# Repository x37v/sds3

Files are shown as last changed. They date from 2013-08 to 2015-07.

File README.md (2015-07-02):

sds3
====

SDS3 clone project - these files have not been succesfully built yet

Long thread on electro-music.com that led to fixes in the original schematic from boardmember Theff, and a working SMT run from xpmtl
http://electro-music.com/forum/topic-16985.html&postorder=asc

some troubleshooting info here: http://electro-music.com/forum/topic-16985-300.html

xpmtl's SMT design is here:
http://xpmtl.net/sdiy/projects/simmons-sds-3-voice/

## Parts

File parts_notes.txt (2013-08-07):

a 2 of 1uF: 	C10, C11
2 of 10u: 	C100, C101
a 1 of 220P: 	C14
a 5 of 100n: 	C2, C13, C15, C102, C103
1 of 470n: 	C3
a 1 of 2N2: 	C4
a 1 of 10uF: 	C5
a 4 of 10n: 	C6, C7, C8, C9
4 of 1N4148_-3: 	D1, D2, D3, D4

3 of 100K: 	[TRIM] GAIN, NULL, OFFSET, 
1 of 47ka: 	DECAY
5 of 100K BEND, DEPTH, IMPACT, PITCH, RATE
1 of 22k: 	TONE

a 4 of LM1458N: 	IC1, IC2, IC3, IC7
a 1 of LM301H: 	IC11
3 of CA3046: 	IC4, IC5, IC6
1 of CA3080LMN: 	IC8

*2 of FB_110: 	L1, L2

ORIGINALLY
	R64: 5.6K
	R65: 3.3K

7 of 100K: R16, R30, R33, R74, R75, R100*, R102
1 of 68R: 	R*
*4 of 390K: 	R11, R14, R55, R69
*3 of 270K: 	R12, R13, R22
*3 of 3K3: 	R18, R41, R104
*5 of 56K: 	R21, R32, R38, R48, R49
4 of 68K: 	R24, R28, R106, R107
7 of 470R: 	R25, R44, R45, R46, R67, R71, R73
*2 of 820R: 	R34, R39
*2 of 22K: 	R35, R56
*7 of 1K: 	R36, R37, R40, R42, R57, R64, R65
*1 of 1K8: 	R43
1 of 3K9: 	R47 [jesse stuffed]
*6 of 150K: 	R5, R6, R8, R23, R27, R29
*6 of 10K: 	R50, R51, R60, R61, R68, R100
*1 of 2M7: 	R52
*1 of 820K: 	R53
*2 of 33K: 	R70, R105
*1 of 10M: 	R76
*3 of 1M: 	R9, R10, R62

1 of shape: 	S1
1 of speed: 	S2
1 of on/off: 	S3
a 2 of BC557B: 	T2, T7
a 3 of 2N5172: 	T3, T6, T8
a 2 of 2N5459: 	T4, T5  [pull off old board]
1 of 057-010-1: 	X1

trimmer holes are too small and only support pins on a line
pads on some of the 8 pin ics are small
r32, r27 labels ambigious
r43 label illegible

need:
68R
68k
470R
3.9K
8 pin sockets
better trimmers: 72-T93YA-100K 
470nF cap [0.47u]

c2, t2 label could be better
c100 and c101 have weird package on board [and should be labeled uF]
Original values for R64 and 65 [add stars?]
R100* is starred because it is fixed at 100K but was part of the run generator before
Actually, there is an R100 and R100*
D7 via is SO close!
S3 and S2 should only have 2 pads
trimmers should be 1 turn..

Alex stuffed 47KA pot with 50K linear

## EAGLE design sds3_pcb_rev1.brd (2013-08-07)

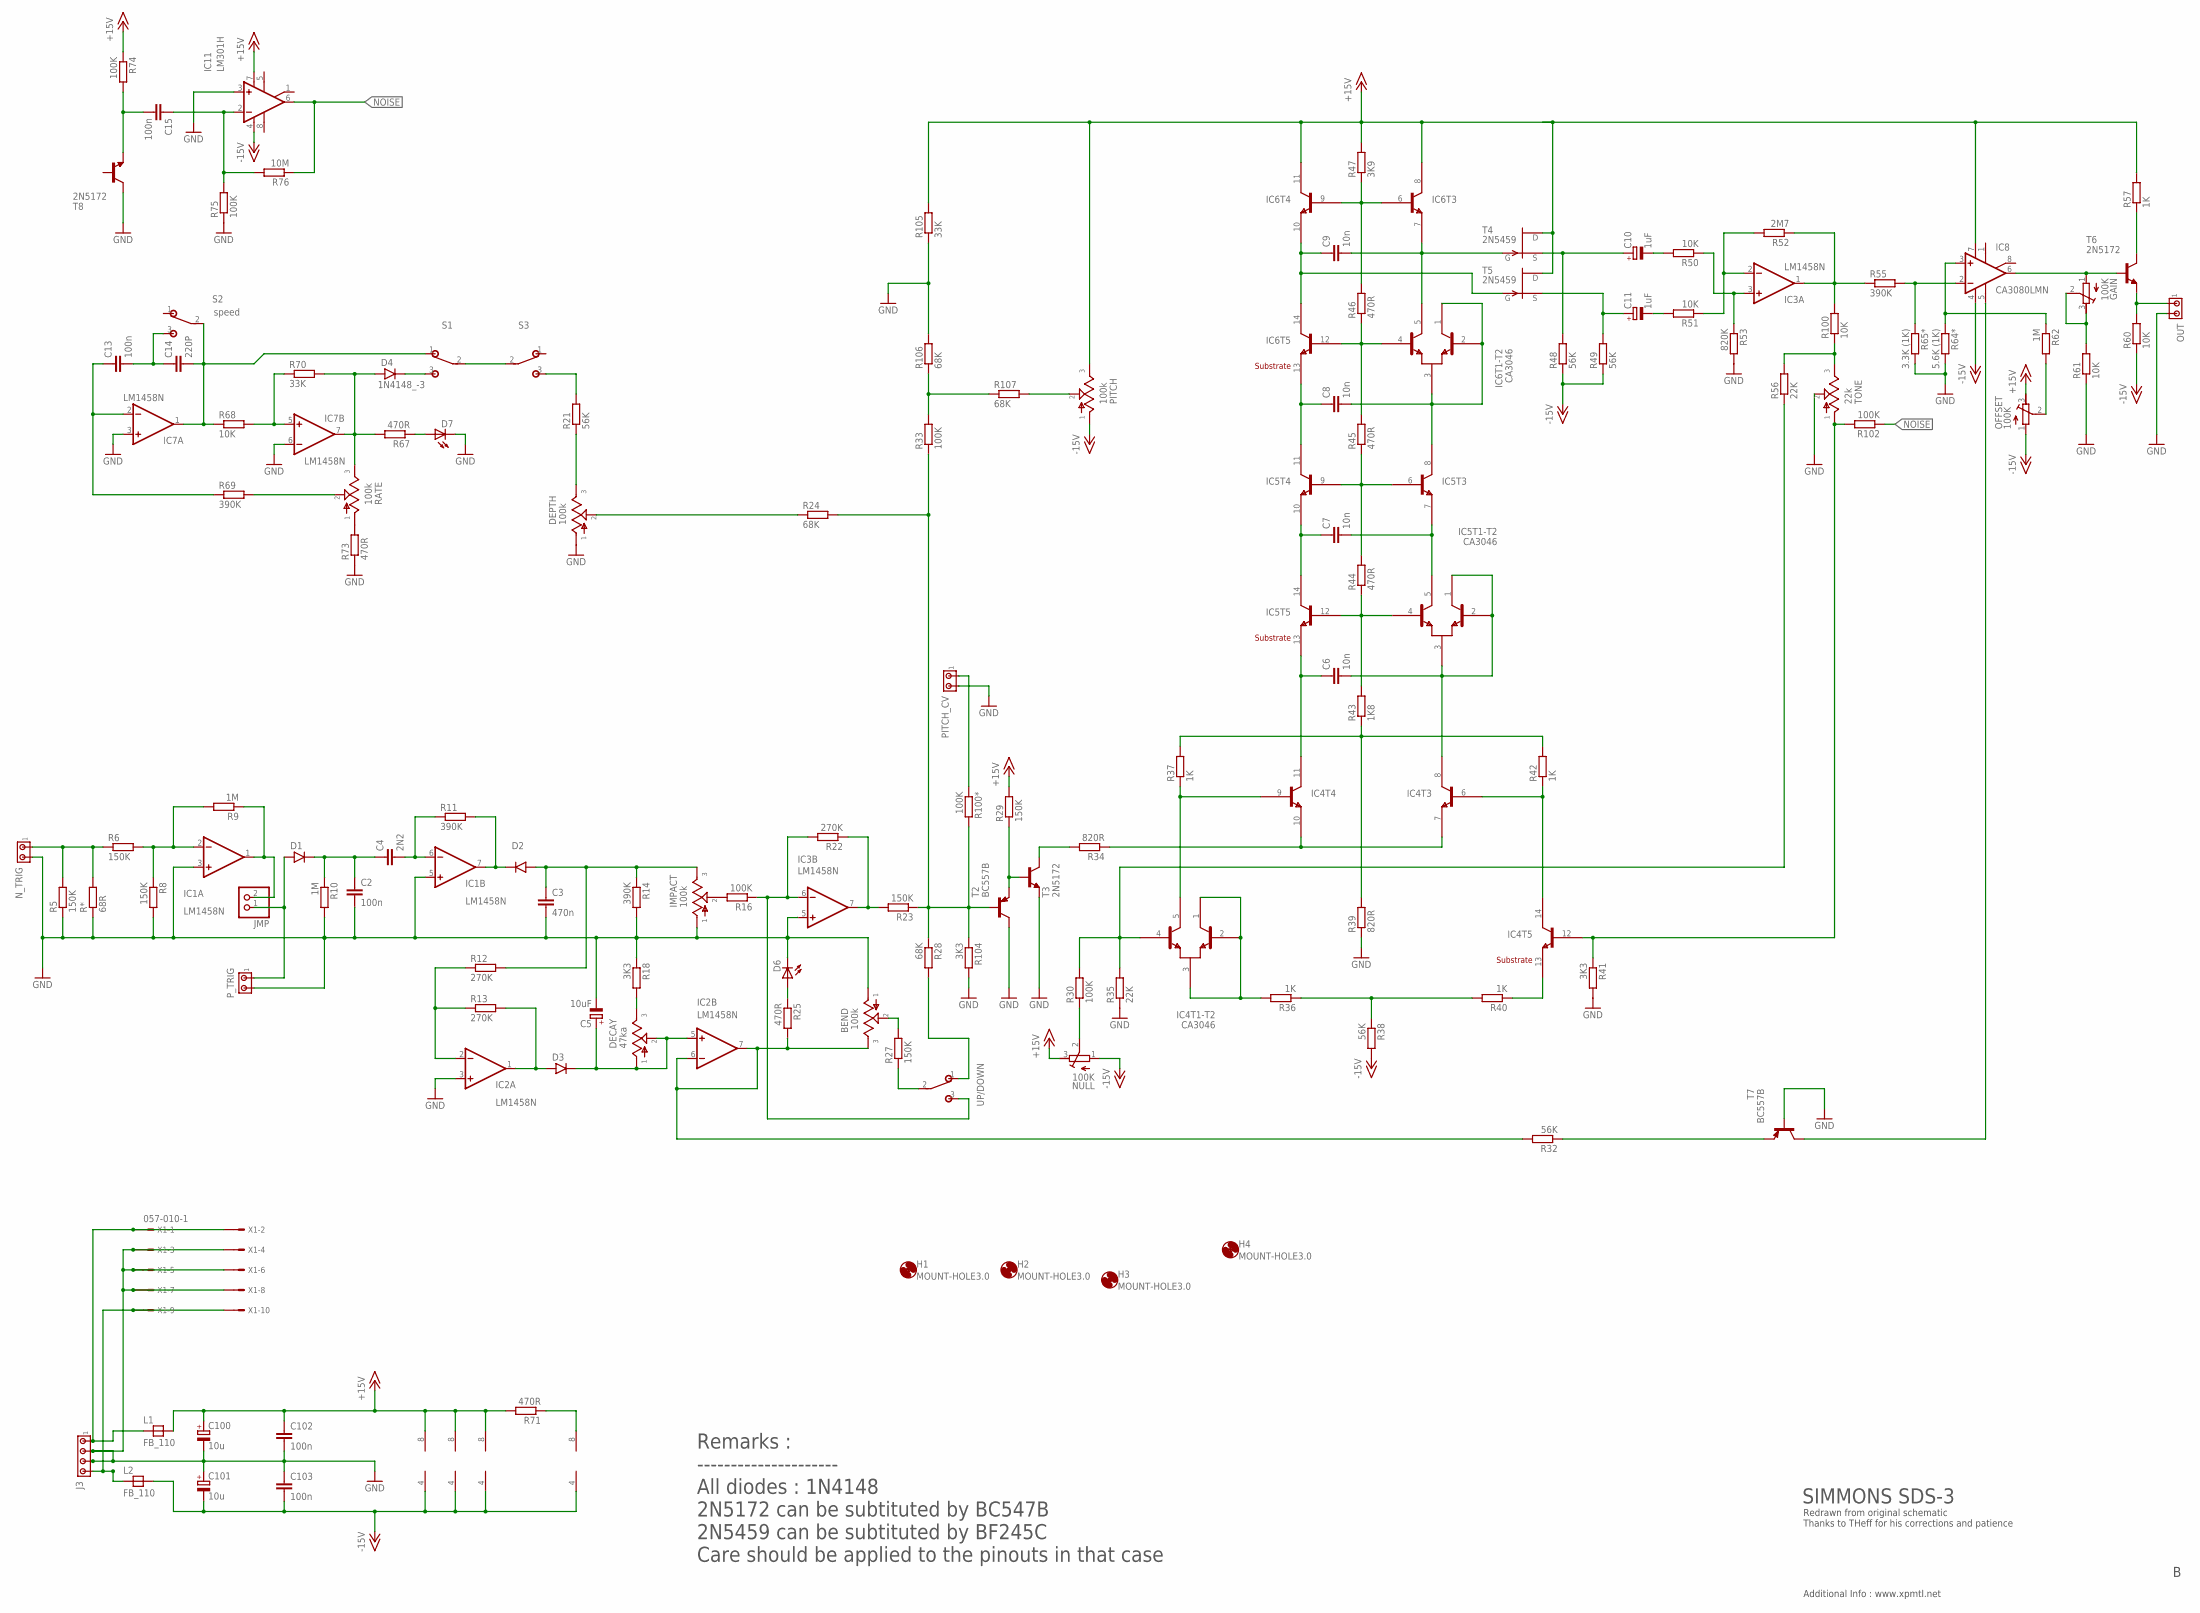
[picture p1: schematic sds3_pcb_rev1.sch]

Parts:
BEND: 100k; POT
C2, C13, C15, C102, C103: 100n; C050-025X075
C3: 470n; C050-025X075
C4: 2N2; C050-025X075
C5: 10uF; E2,5-6
C6, C7, C8, C9: 10n; C050-025X075
C10, C11: 1uF; E2,5-6
C14: 220P; C050-025X075
C100, C101: 10u; B45181A
D1, D2, D3, D4: 1N4148_-3; DO35-3
D6, D7: LED5MM
DECAY: 47ka; POT
DEPTH: 100k; POT
GAIN: 100K; RTRIM3296W
H1, H2, H3, H4: MOUNT-HOLE3.0; 3,0
IC1, IC2, IC3, IC7: LM1458N; DIL08
IC4, IC5, IC6: CA3046; DIL14
IC8: CA3080LMN; DIL08
IC11: LM301H; DIL08
IMPACT: 100k; POT
J3: MTA04-156; 1X4MTA
JMP: PINHD-1X2; 1X02
L1, L2: FB_110; FB-110
NULL: 100K; RTRIM3296W
N_TRIG: MTA02-100; 10X02MTA
OFFSET: 100K; RTRIM3296W
OUT: MTA02-100; 10X02MTA
PITCH: 100k; POT
PITCH_CV: MTA02-100; 10X02MTA
P_TRIG: MTA02-100; 10X02MTA
R5, R6, R8, R23, R27, R29: 150K; 0309V
R9, R10, R62: 1M; 0309V
R11, R14, R55, R69: 390K; 0309V
R12, R13, R22: 270K; 0309V
R16, R30, R33, R74, R75, R100*, R102: 100K; 0309V
R18, R41, R104: 3K3; 0309V
R21, R32, R38, R48, R49: 56K; 0309V
R24, R28, R106, R107: 68K; 0309V
R25, R44, R45, R46, R67, R71, R73: 470R; 0309V
R34, R39: 820R; 0309V
R35, R56: 22K; 0309V
R36, R37, R40, R42, R57: 1K; 0309V
R43: 1K8; 0309V
R47: 3K9; 0309V
R50, R51, R60, R61, R68, R100: 10K; 0309V
R52: 2M7; 0309V
R53: 820K; 0309V
R64*: 5.6K (1K); 0309V
R65*: 3.3K (1K); 0309V
R70, R105: 33K; 0309V
R76: 10M; 0309V
R*: 68R; 0309V
RATE: 100k; POT
S1: shape; SPDT
S2: speed; SPDT
S3: on/off; SPDT
T2, T7: BC557B; TO92-EBC
T3, T6, T8: 2N5172; TO92-LINE
T4, T5: 2N5459; TO92-FET2
TONE: 22k; POT
UP/DOWN: SPDTPADS; SPDT
X1: 057-010-1

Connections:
+15V: C100.+, C102.1, IC1.8 (V+), IC2.8 (V+), IC3.8 (V+), IC6.8 (C), IC6.11 (C), IC8.7 (V+), IC11.7 (V+), L1.2, NULL.3 (E), OFFSET.3 (E), PITCH.3, R29.2, R47.2, R57.2, R71.2, R74.1, R105.2, T4.D, T5.D
-15V: C101.-, C103.2, IC1.4 (V-), IC2.4 (V-), IC3.4 (V-), IC7.4 (V-), IC8.4 (V-), IC11.4 (V-), L2.2, NULL.1 (A), OFFSET.1 (A), PITCH.1, R38.2, R48.1, R49.1, R60.1
GND: BEND.1, C2.2, C3.2, C5.-, C100.-, C101.+, C102.2, C103.1, D6.K (C), D7.K (C), DEPTH.1, IC1.3 (+IN), IC1.5 (+IN), IC2.3 (+IN), IC3.5 (+IN), IC7.3 (+IN), IC7.6 (-IN), IC11.3 (+IN), IMPACT.1, J3.2, J3.3, N_TRIG.2, OUT.2, PITCH_CV.2, P_TRIG.2, R5.1, R8.2, R10.2, R14.2, R18.1, R35.1, R39.1, R41.2, R53.2, R61.1, R64*.2, R65*.2, R73.1, R75.1, R104.2, R105.1, R106.2, R*.1, T2.C, T3.E, T7.B, T8.C, TONE.2, X1.3, X1.4, X1.5, X1.6, X1.7, X1.8
unnamed: C9.1, IC6.10 (E), IC6.14 (C), T5.G
unnamed: IC6.4 (B2), IC6.12 (B), R45.2, R46.1
unnamed: C9.2, IC6.5 (C2), IC6.7 (E), T4.G
unnamed: IC6.6 (B), IC6.9 (B), R46.2, R47.1
unnamed: C11.-, R51.2
unnamed: C8.1, IC5.11 (C), IC6.13 (E)
unnamed: C8.2, IC5.8 (C), IC6.1 (C1), IC6.2 (B1), IC6.3 (E)
unnamed: IC5.6 (B), IC5.9 (B), R44.2, R45.1
unnamed: C7.1, IC5.10 (E), IC5.14 (C)
unnamed: C7.2, IC5.5 (C2), IC5.7 (E)
unnamed: IC5.4 (B2), IC5.12 (B), R43.2, R44.1
unnamed: C6.1, IC4.11 (C), IC5.13 (E)
unnamed: C6.2, IC4.8 (C), IC5.1 (C1), IC5.2 (B1), IC5.3 (E)
unnamed: IC4.6 (B), IC4.14 (C), R42.1
unnamed: IC4.5 (C2), IC4.9 (B), R37.1
unnamed: R37.2, R39.2, R42.2, R43.1
unnamed: IC4.7 (E), IC4.10 (E), R34.1
unnamed: IC4.1 (C1), IC4.2 (B1), IC4.3 (E), R36.2
unnamed: R36.1, R38.1, R40.2
unnamed: IC4.13 (E), R40.1
unnamed: IC4.4 (B2), R30.2, R35.2, R56.1
unnamed: C10.-, R50.2
unnamed: C10.+, R48.2, T4.S
unnamed: C11.+, R49.2, T5.S
unnamed: IC3.3 (+IN), R50.1, R53.1
unnamed: IC3.2 (-IN), R51.1, R52.2
unnamed: IC3.1 (OUT), R52.1, R55.1, R100.2
unnamed: IC8.2 (-IN), R55.2, R65*.1
unnamed: IC8.3 (+IN), R62.1, R64*.1
unnamed: GAIN.1 (A), IC8.6 (OUT), T6.B
unnamed: R57.1, T6.C
unnamed: OUT.1, R60.2, T6.E
unnamed: R32.1, T7.E
unnamed: IC8.5 (OPT), T7.C
unnamed: R56.2, R100.1, TONE.3
unnamed: IC4.12 (B), R41.1, R102.2, TONE.1
unnamed: OFFSET.2 (S), R62.2
unnamed: NULL.2 (S), R30.1
unnamed: R23.1, R24.2, R28.1, R33.1, R100*.2, R104.1, T2.B
unnamed: R29.1, T2.E, T3.B
unnamed: R34.2, T3.C
unnamed: IC3.7 (OUT), R22.1, R23.2
unnamed: IC3.6 (-IN), R16.1, R22.2, UP/DOWN.3 (S)
unnamed: IC1.1 (OUT), JMP.2, R9.1
unnamed: IMPACT.2, R16.2
unnamed: C3.1, D2.A, IMPACT.3, R12.2, R14.1
unnamed: D2.C, IC1.7 (OUT), R11.2
unnamed: C4.2, IC1.6 (-IN), R11.1
unnamed: C2.1, C4.1, D1.C, R10.1
unnamed: IC2.2 (-IN), R12.1, R13.1
unnamed: IC1.2 (-IN), R6.2, R8.1, R9.2
unnamed: N_TRIG.1, R5.2, R6.1, R*.2
unnamed: D3.A, IC2.1 (OUT), R13.2
unnamed: BEND.3, IC2.6 (-IN), IC2.7 (OUT), R25.2, R32.2
unnamed: C5.+, D3.C, DECAY.1, DECAY.2, IC2.5 (+IN)
unnamed: DECAY.3, R18.2
unnamed: D6.A, R25.1
unnamed: R27.1, UP/DOWN.2
unnamed: BEND.2, R27.2
unnamed: R28.2, UP/DOWN.1 (O)
unnamed: R21.2, S3.3 (S)
unnamed: C15.2, R74.2, T8.E
unnamed: C15.1, IC11.2 (-IN), R75.2, R76.2
unnamed: PITCH_CV.1, R100*.1
unnamed: R73.2, RATE.1
unnamed: GAIN.2 (S), GAIN.3 (E), R61.2
unnamed: C14.2, IC7.1 (OUT), R68.1, S1.1 (O), S2.2
unnamed: IC7.5 (+IN), R68.2, R70.1
unnamed: D4.A, IC7.7 (OUT), R67.2, R70.2, RATE.3
unnamed: R69.2, RATE.2
unnamed: C13.1, IC7.2 (-IN), R69.1
unnamed: C13.2, C14.1, S2.3 (S)
unnamed: D4.C, S1.3 (S)
unnamed: S1.2, S3.2
unnamed: DEPTH.3, R21.1
unnamed: DEPTH.2, R24.1
unnamed: PITCH.2, R107.2
unnamed: R33.2, R106.1, R107.1
unnamed: D7.A, R67.1
unnamed: J3.1, L1.1, X1.1, X1.2
unnamed: J3.4, L2.1, X1.9, X1.10
unnamed: IC7.8 (V+), R71.1
unnamed: D1.A, JMP.1, P_TRIG.1
NOISE: IC11.6 (OUT), R76.1, R102.1

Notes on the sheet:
SIMMONS SDS-3
Redrawn from original schematic Thanks to THeff for his corrections and patience
Remarks : --------------------- All diodes : 1N4148 2N5172 can be subtituted by BC547B 2N5459 can be subtituted by BF245C Care should be applied to the pinouts in that case
Additional Info : www.xpmtl.net

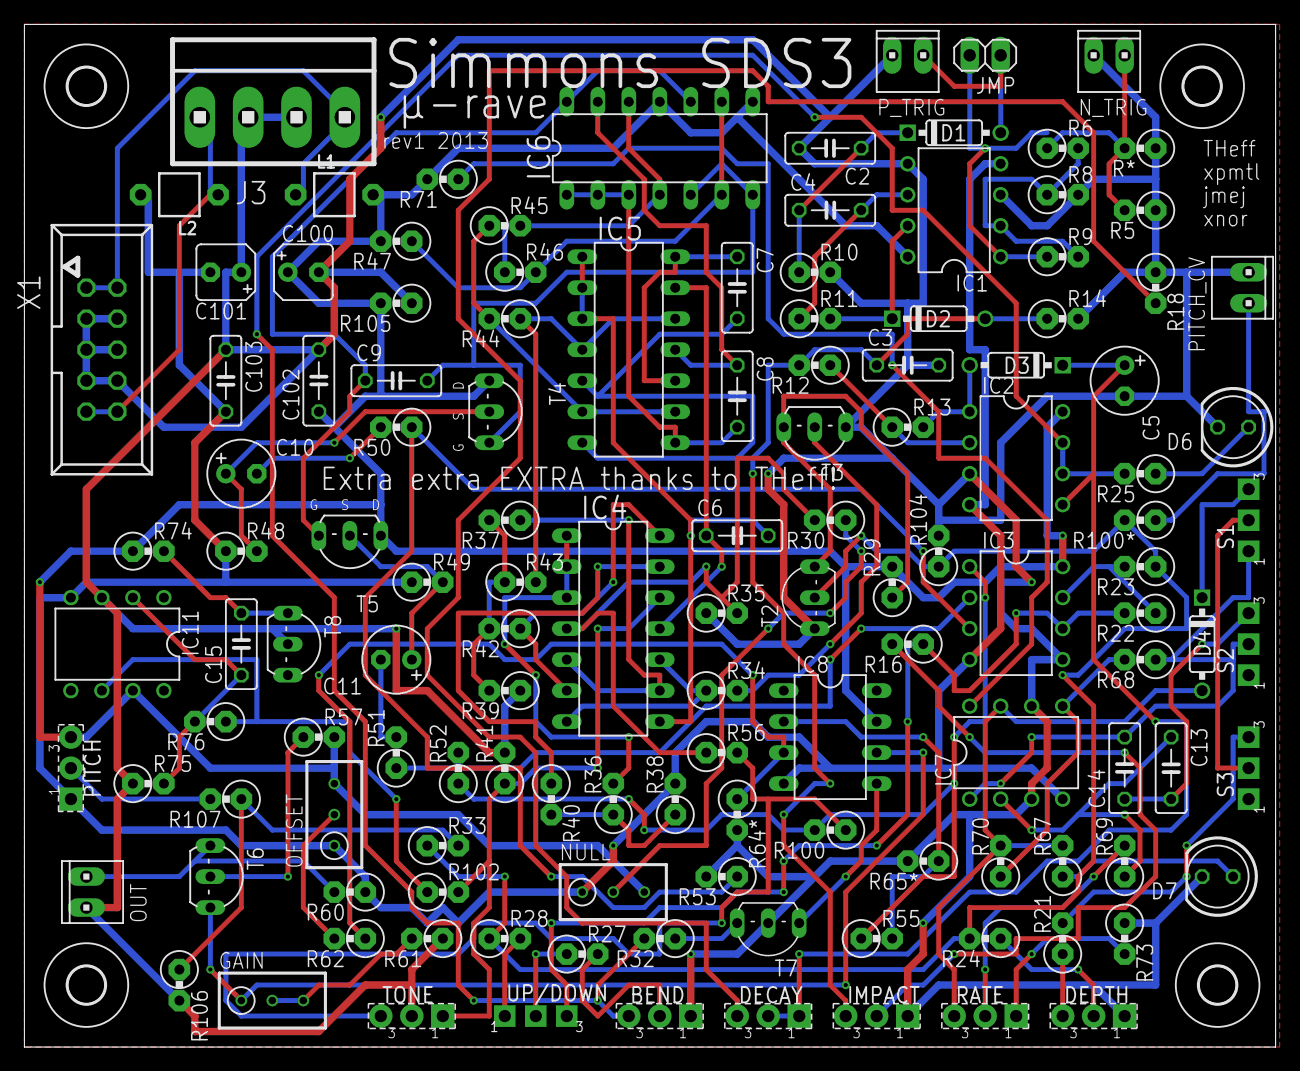
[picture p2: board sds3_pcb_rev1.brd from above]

Board: 2 copper layers, 102.5 x 83.8 mm, 133 parts (0 on the bottom side), 87 nets.
